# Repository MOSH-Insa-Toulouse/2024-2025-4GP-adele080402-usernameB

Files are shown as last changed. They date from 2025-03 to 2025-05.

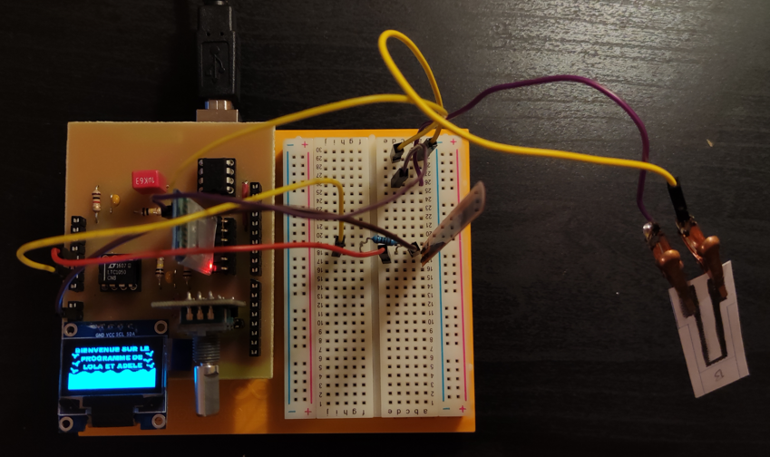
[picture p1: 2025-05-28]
Images Projet/Montage_arduino.png

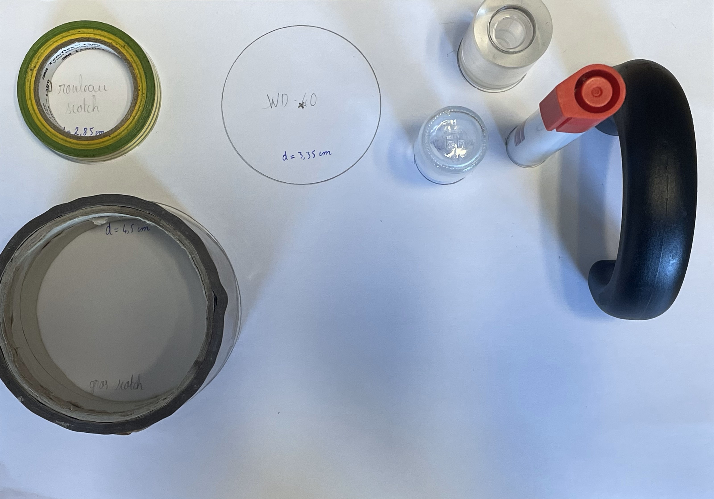
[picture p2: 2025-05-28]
Images Projet/Banc-de-test.jpg

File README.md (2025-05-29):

# PROJET CAPTEUR

## Sommaire
- [Description du projet](#description-du-projet)
- [Livrables](#livrables)
- [Matériel utilisé](#matériel-utilisé)
- [Simulation du montage sur LTSpice](#simulation-du-montage-sur-ltspice)
- [Création du PCB](#création-du-pcb)  
    -[KiCad](#kicad)  
    -[Schéma complet](#kicad)  
    -[Impression du PCB](#impression-du-pcb)  
- [Code Arduino](#code-arduino)
- [Application Android](#application-android)
- [Datasheet](#datasheet)
- [Tests de notre capteur et relevé de valeurs](#tests-de-notre-capteur-et-relevé-de-valeurs)
- [Contact](#contact)

## Description du projet

Nous avons réalisé ce projet dans le cadre de l'UF "du capteur au banc de test en open source hardware", en 4ème année de Génie Physique à l'INSA de Toulouse.
Le but de ce projet, basé sur l'article "Pencil Drawn Strain Gauges and Chemiresistors on Paper" (Cheng-Wei Lin, Zhibo Zhao, Jaemyung Kim & Jiaxing Huang), est de réaliser et tester un capteur low-tech, et d'évaluer son fonctionnement par rapport à un capteur commercialisé, afin de voir s'il est lui-même industrialisable. Le capteur concerné s'apparente à une jauge de contrainte, réalisée avec du papier recouvert d'une couche de graphite.  
Pour ce faire, nous avons réalisé un PCB à partir du logiciel KiCad, que nous avons pu intégrer à une carte Arduino UNO. Cela nous a permis d'effectuer des mesures et de tester notre capteur.

## Livrables

- PCB Shield adapté à l'Arduino Uno
- Code Arduino complet
- Banc de test du capteur
- Application Android fonctionnant par Bluetooth
- Datasheet du capteur

## Matériel utilisé

- Écran OLED : SSD1306
- Flex sensor
- Capteur Graphène
- Encodeur Rotatoire : KY-040
- Module Bluetooth HC-05
- Amplificateur Opérationnel : LCT-1050
- Potentiomètre Digital : MCP 41050
- Résistances : 1kOhms, 10kOhms, 100kOhms
- Capacités : 2x100nF, 1x1uF

## Simulation du montage sur LTSpice

Avant de commencer la réalisation concrète de notre projet, nous avons réalisé le montage qui sera réalisé physiquement sur [LTSpice](./LTSpice). Cette simulation nous a permis de comprendre comment l'arduino Uno pouvait acquérir les données du capteur. En effet, sans mettre en place un circuit transimpédance, nous ne serions pas en capacité d'acquérir des valeurs de résistance aussi élevées (k-M Ohms), puisque le courant résultant à acquérir avec un générateur 5V est très faible.

montage avec capteur image

## Création du PCB
### KiCad

Pour commencer le projet, nous avons dû nous familiariser avec le logiciel KiCad. Au début, nous avons eu du mal à assimiler les différentes étapes à effectuer, à cause de la diversité de ces dernières dans le logiciel KiCad. Nous avons finalement réussi à imprimer notre PCB dans les temps et sans problème. 
Premièrement, nous avons dû reprendre le circuit que nous avions réalisé sur LTSpice qui simulait le circuit final.  

Nous avons pris ce modèle pour réaliser la [partie schématique](./KiCad-Shield-Uno-FlexSensor) sur KiCad. Nous avons modélisé le circuit amplificateur, ainsi que différents dispositifs également présents sur notre PCB : 

- le [potentiomètre digital](./KiCad-Shield-Uno-FlexSensor/MaLibrairieEmpreinte.pretty)  

- l'[encodeur rotatoire](./KiCad-Shield-Uno-FlexSensor/MaLibrairieEmpreinte.pretty) 

- l'[écran OLED](./KiCad-Shield-Uno-FlexSensor/MaLibrairieEmpreinte.pretty)

- le [module Bluetooth](./KiCad-Shield-Uno-FlexSensor/MaLibrairieEmpreinte.pretty)
  
- l'[amplificateur opérationnel LTC41050](./KiCad-Shield-Uno-FlexSensor/MaLibrairieEmpreinte.pretty)

Ensuite, lorsque nous avons terminé le schématique, nous avons pu passer à l'organisation des éléments du PCB. Après avoir créé les empreintes et importer les bons modèles 3D des différents éléments, nous avons dû disposer de manière la plus optimale ces derniers. Cette étape a été un peu longue et nous avons dû recommencer plusieurs fois afin de limiter le nombre de vias et trouver la meilleure organisation possible. Nous avons finalement réussi à réaliser notre PCB avec seulement 3 vias. Nous avons également utilisé un plan de masse afin de simplifier le circuit.   
Une fois validé, nous avons pu passer à l'impression.

### Schéma complet

Schématique du PCB

                                            Schématique du PCB

Routage terminé du PCB

                                          Routage terminé du PCB
                                          
Modèle 3D du PCB (face avant)

                                          Modèle 3D du PCB (face avant)
                                            
Modèle 3D du PCB (face arrière)

                                          Modèle 3D du PCB (face arrière)

### Impression du PCB

Pour imprimer le PCB, nous avons dû télécharger le fichier [.gerber](./KiCad-Shield-Uno-FlexSensor/Gerber/KiCad-Shield-Uno-FlexSensor-B_Cu.pdf). Nous avons envoyé tous nos fichiers KiCad à Catherine Crouzet, qui nous a donné rendez-vous au GEI. Sur place, elle nous a expliqué toute la procédure. Le développement a été fait grâce au masque (fichier Gerber) placé sur une plaquette vierge et passé aux UVs, puis aux bains de développement.  
Une fois la plaquette dessinée, nous sommes allées percer la plaquette (les diamètres sont de 0,8mm pour les composants, et 1mm pour les pins de l'Arduino) sur laquelle nous avons soudé tous les composants. Cette partie était relativement rapide.



                                             Fichier Gerber
                                             


                                              PCB imprimé
                                              
PCB-avec-composants-avant

                                      PCB avec les composants soudés

## Code Arduino

Nous avons ensuite rédigé le [code](./arduino_code_capteur/arduino_code_capteur.ino) .ino, écrit en C++.   
Pour ce faire, nous nous sommes inspirées des codes étudiés durant les TPs/TDs tout au long du deuxième semestre, qui nous ont permis de mieux comprendre comment fonctionnait chaque composant.  
Nous avons rédigé les codes de chaque composant indépendamment afin de pouvoir les tester un à un, puis nous avons écrit le code en rajoutant peu à peu les codes fonctionnels et en les reliant les uns aux autres.

Le plus difficile à coder était l'encodeur rotatoire. Nous avons essayé de nombreuses fois, en nous inspirant des codes des années précédentes, ou des codes présents sur internet comme [Passion Électronique](https://passionelectronique.fr/encodeur-rotatif-incremental-mecanique/).  
Cependant, nous n'avons pas réussi à écrire un code fonctionnel qui nous permettait de naviguer entre les menus que nous avions créés. Nous avons décidé de garder les menus pour les différents composants (flex sensor, graphite sensor et potentiomètre digital) dans le code, pour pouvoir y accéder si besoin, ainsi que si de prochaines personnes voulaient essayer de rajouter la navigation entre les menus.   
Nous avons néanmoins voulu utiliser l'encodeur rotatoire, donc nous avons ajouté une fonction permettant de faire varier la valeur du potentiomètre digital grâce à l'encodeur.  

Nous n'avons malheureusement pas eu le loisir d'être très créatives car nous avons passé beaucoup de temps à décortiquer le fonctionnement et l'écriture du code pour chaque composant. Nous avons tout de même souhaité personnaliser notre projet en rajoutant un écran d'accueil à l'initialisation de l'écran OLED, qu'on peut voir sur la photo ci-dessous. 

E´cran_accueil_OLED

                                              Écran d'accueil de l'OLED

## Application Android

Pour l'[application Android](./Application Android), nous avons rencontré de nombreux problèmes au cours de son développement sur [MIT App Inventor](https://appinventor.mit.edu/). Le premier était simplement un problème d'affichage des données récupérer sur le graphique intéractif. Mais par la suite, nous ne pouvions même plus connecter notre téléphone à l'application, ce qui a nettement ralenti le développement de cette dernière, ainsi que son résultat final.  
Nous avons finalement une application à laquelle nous pouvons nous connecter, qui récupère les données affichées simultanément sur l'écran OLED, trace un graphique en temps réel, et contient un bouton RESET.

Écran_app_graphe_bonformat

                                              Interface de l'application Android

## Datasheet

Pour écrire la [datasheet](./Datasheet_capteur.pdf), nous avons décrit toutes les spécifités de notre capteur, tout en essayant de bien en expliquer son fonctionnement. Nous nous sommes basées sur les datasheets que nous avons pu étudier en cours au début du semestre, ainsi que toutes celles utilisées dans le cadre de nos études ou vies personnelles. La datasheet donne également un exemple d'application que l'on a expérimenté  au cours de ce projet.

## Tests de notre capteur et relevé de valeurs

Capture d'écran 2025-05-22 152802

Capture d'écran 2025-05-22 152732

Pour les relevés de valeur, nous avons rencontré un problème de consistance dans les mesures.
Le banc de test n'étant pas disponible lors de nos relevés de mesure, nous avons dû improviser et tester le capteur avec des objets circulaires dont le diamètre variait suffisamment pour avoir des données pertinentes. Ci-dessous est une photo des objets que nous avons utilisés.

Banc-de-test

                                        Objets utilisés pour le banc de test et leurs diamètres

Nous avons essayé de suivre un protocole de mesure afin d'avoir les mesures les plus pertinentes possible. Cependant, nous n'avons pas eu des mesures très satisfaisantes. 
Plus la mine de crayon est dure (2H), plus le capteur va être sensible et les valeurs vont fluctuer significativement, alors même que le capteur est immobile et qu'on n'y applique aucune déformation.
Inversement, plus la mine de crayon est grasse (6B), moins le capteur va être sensible et les valeurs vont rester très stables. On n'observera donc aucun changement de résistance, même en appliquant une forte déformation.

Aussi la manière de déposer le graphite influence beaucoup les valeurs obtenues.

Nous avons réussi à relever des valeurs uniquement pour les mines B et HB. Pour les autres mines testées, les valeurs n'étaient malheureusement pas pertinentes.

- HB : Mine avec laquelle le relevé de données a été concluant en compression mais moins en extension.
- B : Mine avec laquelle le relevé de données a été le plus concluant.
- 6B :Les valeurs de résistance mesurées avec cette mine restent bloquées à une valeur :  à 650 MOhms, même si la déformation appliquée est très importante.
- 2H : Les valeurs de résistance mesurées fluctuent trop, nous ne parvenons pas à avoir de données stables.

## Contact

Pour toute question ou information complémentaire, vous pouvez nous contacter :  
•Adèle Hovnanian, hovnanian@insa-toulouse.fr  
•Lola Grammont, grammont@insa-toulouse.fr

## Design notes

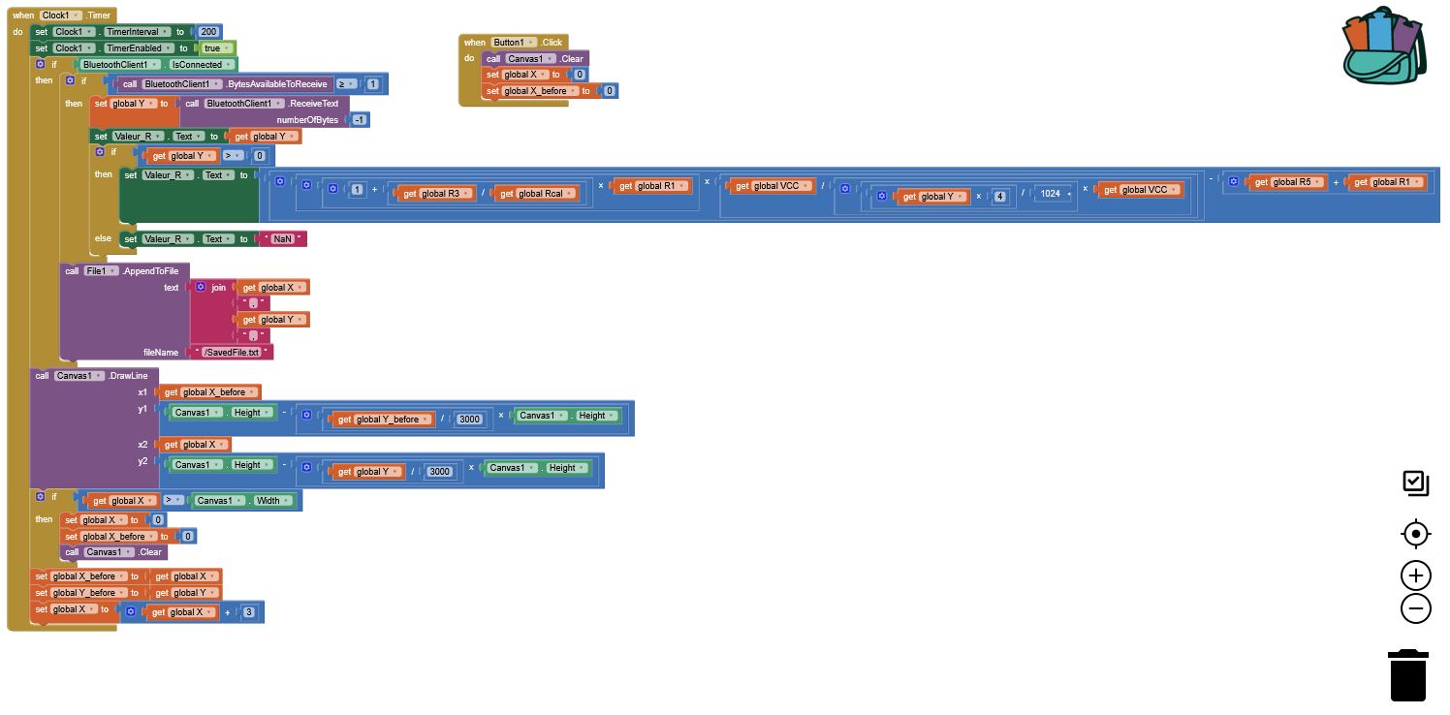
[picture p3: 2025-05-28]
Images Projet/application/Blocs_de_code_2.png

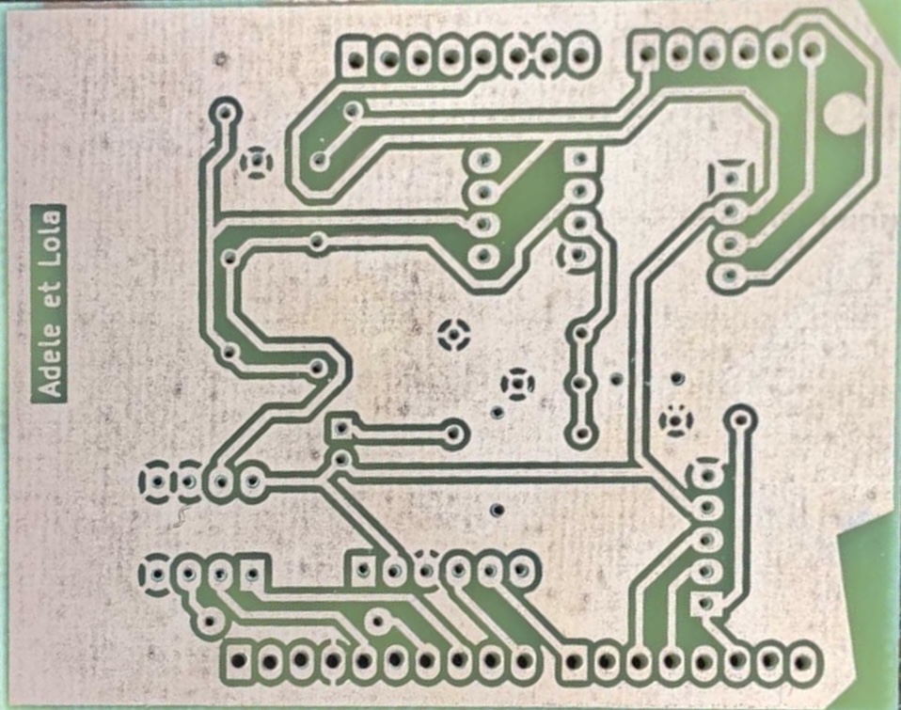
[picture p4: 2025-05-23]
Images Projet/PCB_imprime.jpg

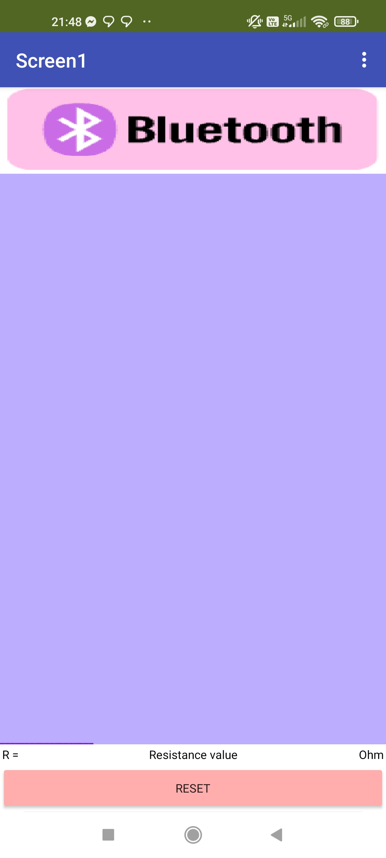
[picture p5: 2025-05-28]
Images Projet/application/Écran_app_vierge.jpg

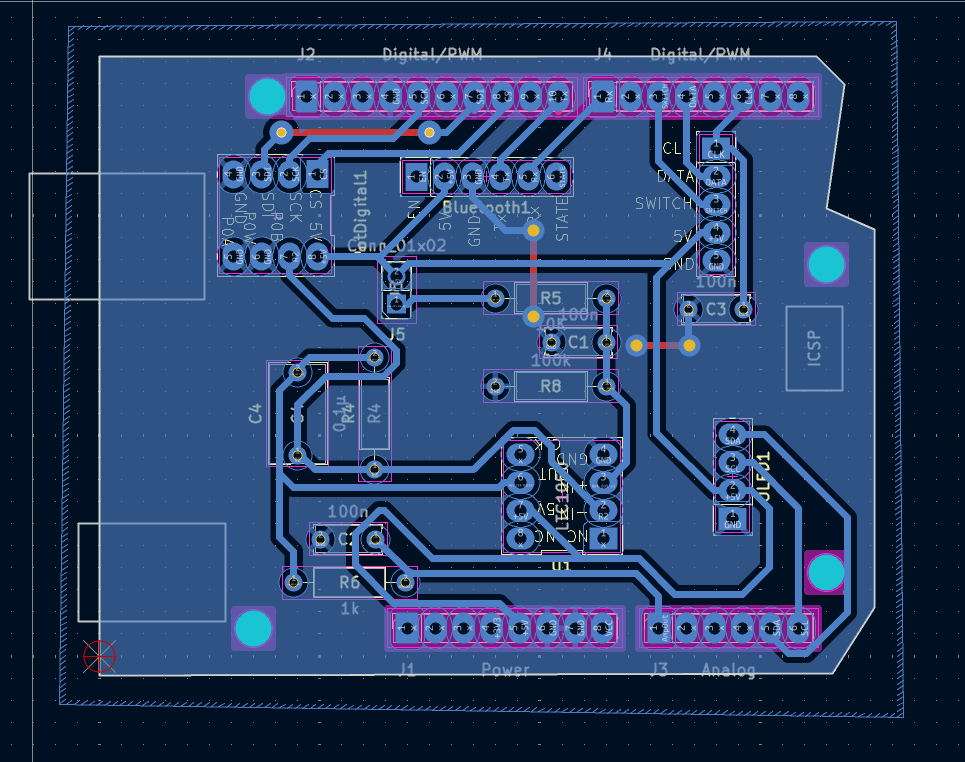
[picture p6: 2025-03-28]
Images Projet/Photos_kicad/Routage_KiCad.png

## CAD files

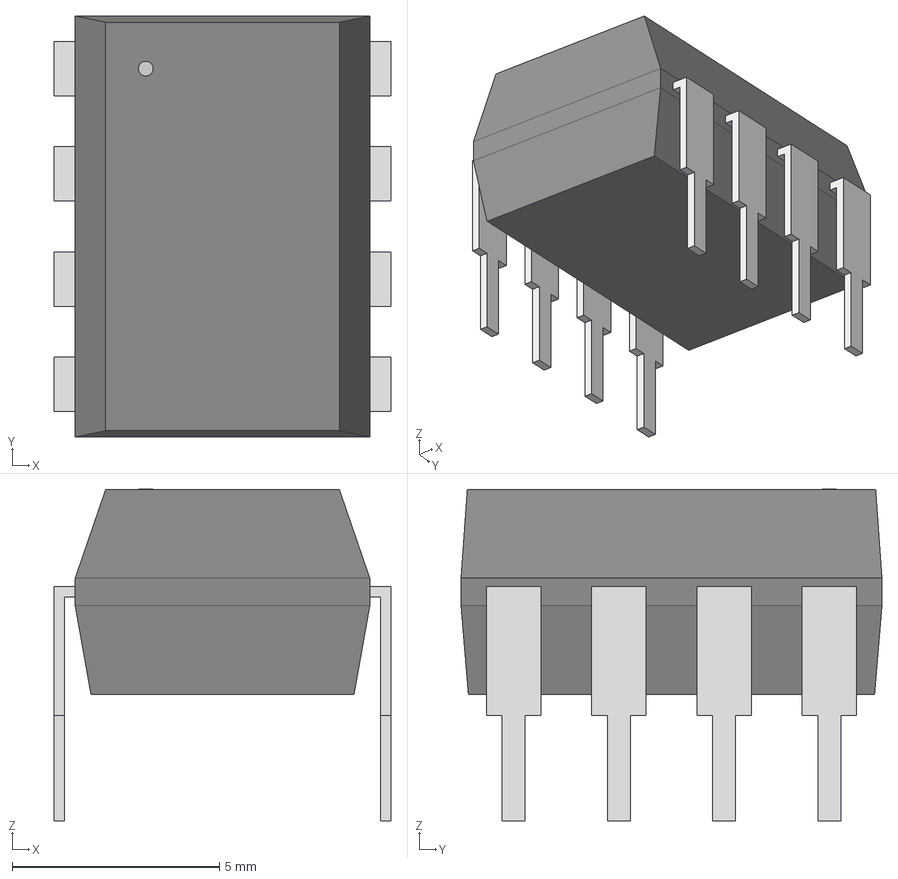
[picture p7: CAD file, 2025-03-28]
KiCad-Shield-Uno-FlexSensor/modeles_3D/MCP41050_E_P(1)/PDIP8_300MC_MCH.step
8.13 x 10.2 x 8.00 mm

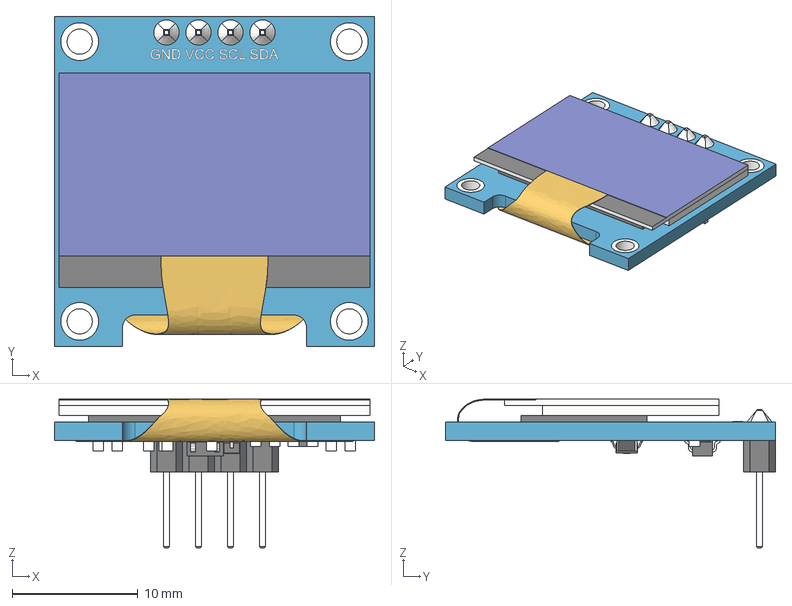
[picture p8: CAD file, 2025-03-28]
KiCad-Shield-Uno-FlexSensor/modeles_3D/SSD1306_OLED_Display(128x64).step
25.4 x 26.2 x 11.8 mm
board
screen
pin_header
soldering
smd_capacitor
smd_capacitor (1)
914_smd_resistor
472_smd_resistor x 3
t4_smd_diode
smd_capacitor (2)
smd_capacitor (3)
smd_capacitor (4)
smd_capacitor (5)
smd_capacitor (6)
472_smd_resistor (1)
SOT-23_XC6206 v3
smd_capacitor (7)
flat_cable

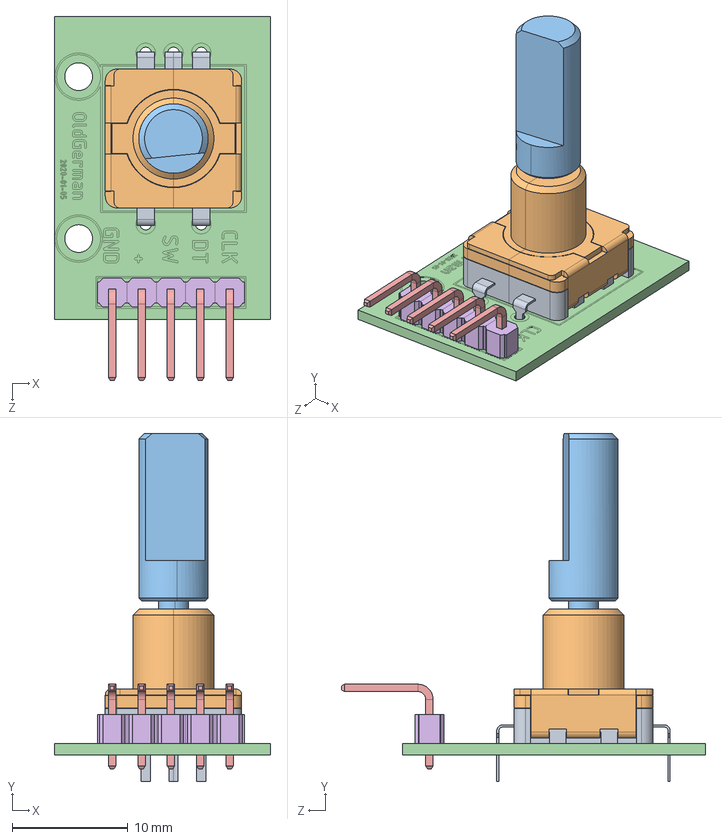
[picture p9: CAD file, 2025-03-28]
KiCad-Shield-Uno-FlexSensor/modeles_3D/KY-040 Rotary Encoder.STEP
18.7 x 30.1 x 31.5 mm
Rotary Encoder
D-handle
pcb
2.54 5PIN 90

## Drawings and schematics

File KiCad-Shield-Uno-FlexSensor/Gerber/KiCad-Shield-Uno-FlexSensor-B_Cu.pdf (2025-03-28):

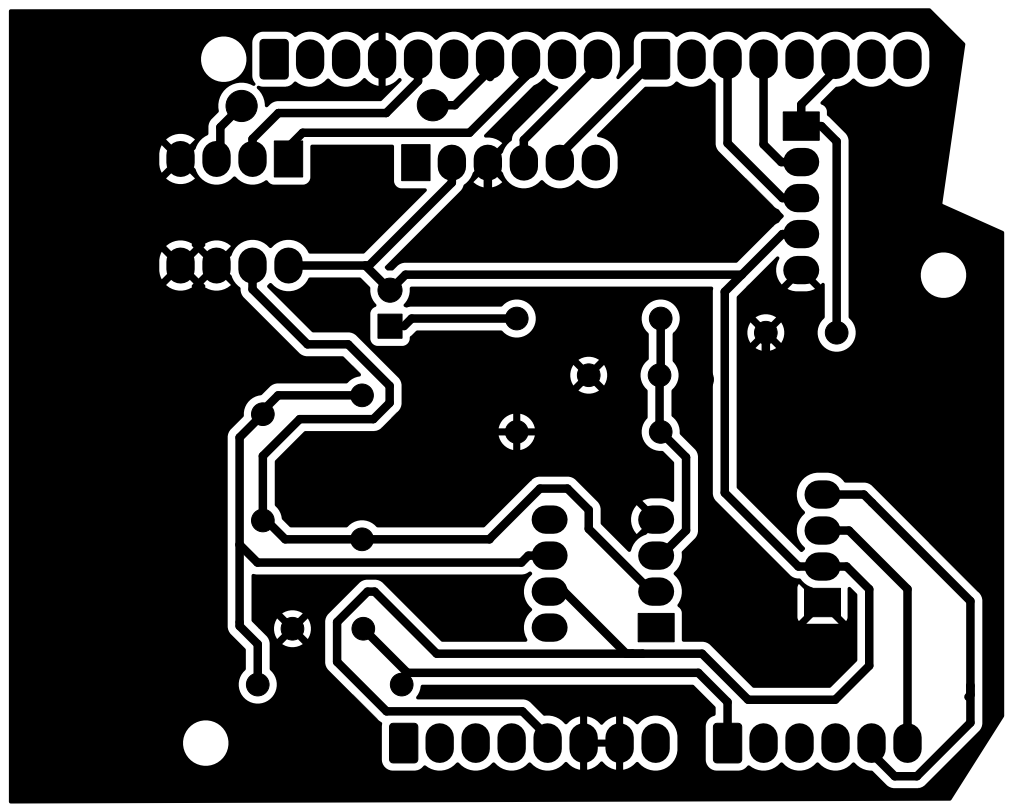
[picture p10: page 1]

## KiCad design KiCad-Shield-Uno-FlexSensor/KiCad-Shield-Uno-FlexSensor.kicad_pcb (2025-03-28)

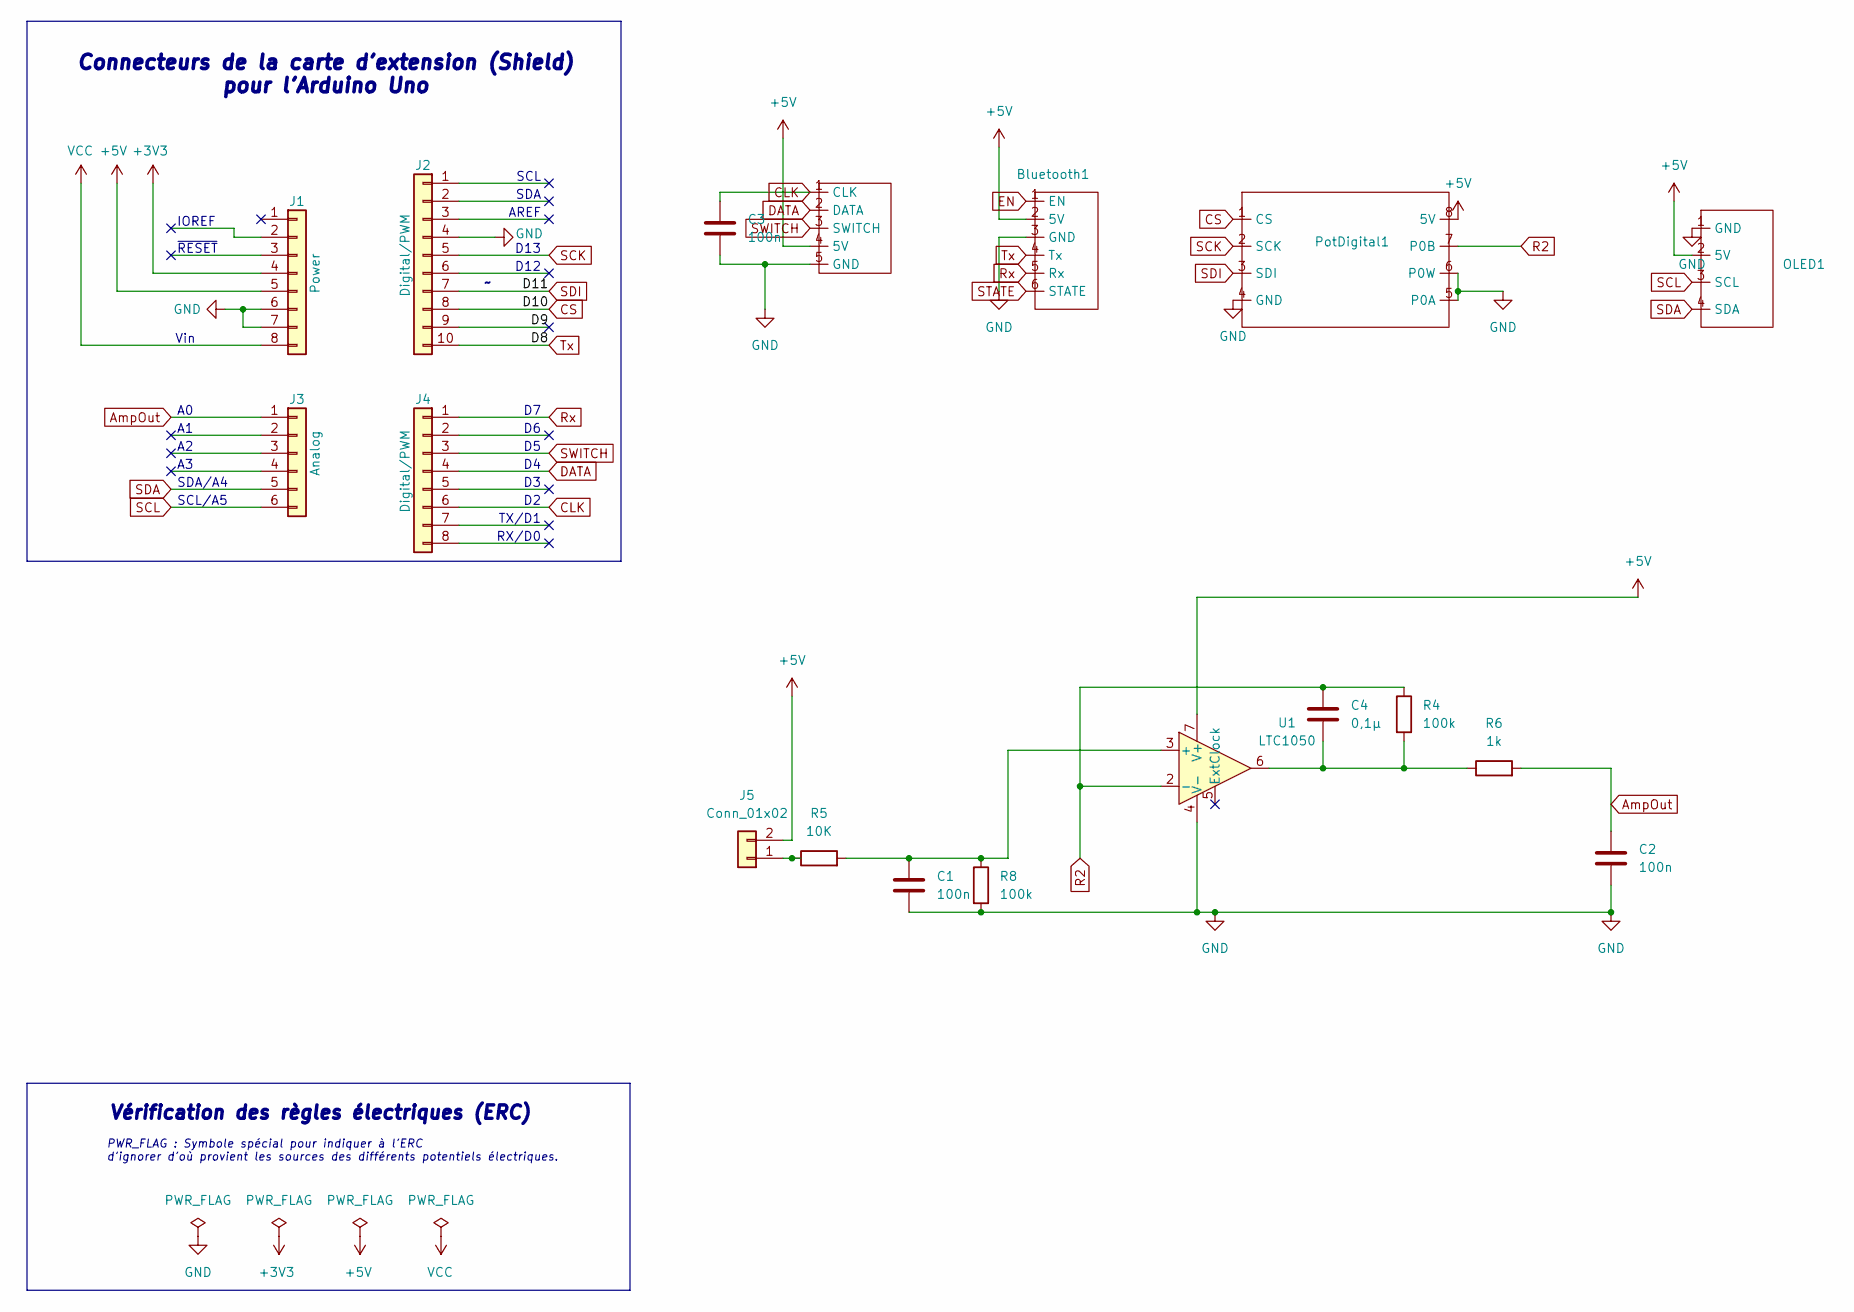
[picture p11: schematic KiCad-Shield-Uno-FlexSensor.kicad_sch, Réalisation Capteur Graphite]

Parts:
Bluetooth1: Bluetooth
C1, C2, C3: 100n; C_Disc_D6.0mm_W2.5mm_P5.00mm
C4: 0,1µ; C_Rect_L9.0mm_W5.1mm_P7.50mm_MKT
Encodeur_rotatoire1: EncodeurRotatoire
J1: Power; PinSocket_1x08_P2.54mm_Vertical
J2: Digital/PWM; PinSocket_1x10_P2.54mm_Vertical
J3: Analog; PinSocket_1x06_P2.54mm_Vertical
J4: Digital/PWM; PinSocket_1x08_P2.54mm_Vertical
J5: Conn_01x02; PinSocket_1x02_P2.54mm_Vertical
OLED1: OLED
PotDigital1: PotDigital
R4, R8: 100k; R_Axial_DIN0207_L6.3mm_D2.5mm_P10.16mm_Horizontal
R5: 10K; R_Axial_DIN0207_L6.3mm_D2.5mm_P10.16mm_Horizontal
R6: 1k; R_Axial_DIN0207_L6.3mm_D2.5mm_P10.16mm_Horizontal
U1: LTC1050; LTC41050

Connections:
+3V3: J1.4
+5V: Bluetooth1.2 (5V), Encodeur_rotatoire1.4 (5V), J1.5, J5.2, OLED1.2 (5V), PotDigital1.8 (5V), U1.7 (V+)
/D9: J2.9
AmpOut: C2.1, J3.1, R6.2
CLK: C3.1, Encodeur_rotatoire1.1 (CLK), J4.6
CS: J2.8, PotDigital1.1 (CS)
DATA: Encodeur_rotatoire1.2 (DATA), J4.4
EN: Bluetooth1.1 (EN)
GND: Bluetooth1.3 (GND), C1.2, C2.2, C3.2, Encodeur_rotatoire1.5 (GND), J1.6, J1.7, J2.4, OLED1.1 (GND), PotDigital1.4 (GND), PotDigital1.5 (P0A), PotDigital1.6 (P0W), R8.2, U1.4 (V-)
unnamed: C4.2, R4.2, R6.1, U1.6
unnamed: J5.1, R5.1
unnamed: C1.1, R5.2, R8.1, U1.3 (+)
R2: C4.1, PotDigital1.7 (P0B), R4.1, U1.2 (-)
Rx: Bluetooth1.5 (Rx), J4.1
SCK: J2.5, PotDigital1.2 (SCK)
SCL: J3.6, OLED1.3 (SCL)
SDA: J3.5, OLED1.4 (SDA)
SDI: J2.7, PotDigital1.3 (SDI)
STATE: Bluetooth1.6 (STATE)
SWITCH: Encodeur_rotatoire1.3 (SWITCH), J4.3
Tx: Bluetooth1.4 (Tx), J2.10
VCC: J1.8

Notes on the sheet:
AREF
SDA/A4
D12
~{RESET}
RX/D0
TX/D1
D13
Vin
SDA
Vérification des règles électriques (ERC)
Connecteurs de la carte d'extension (Shield) pour l'Arduino Uno
SCL/A5
SCL
IOREF
PWR_FLAG : Symbole spécial pour indiquer à l'ERC d'ignorer d'où provient les sources des différents potentiels électriques.

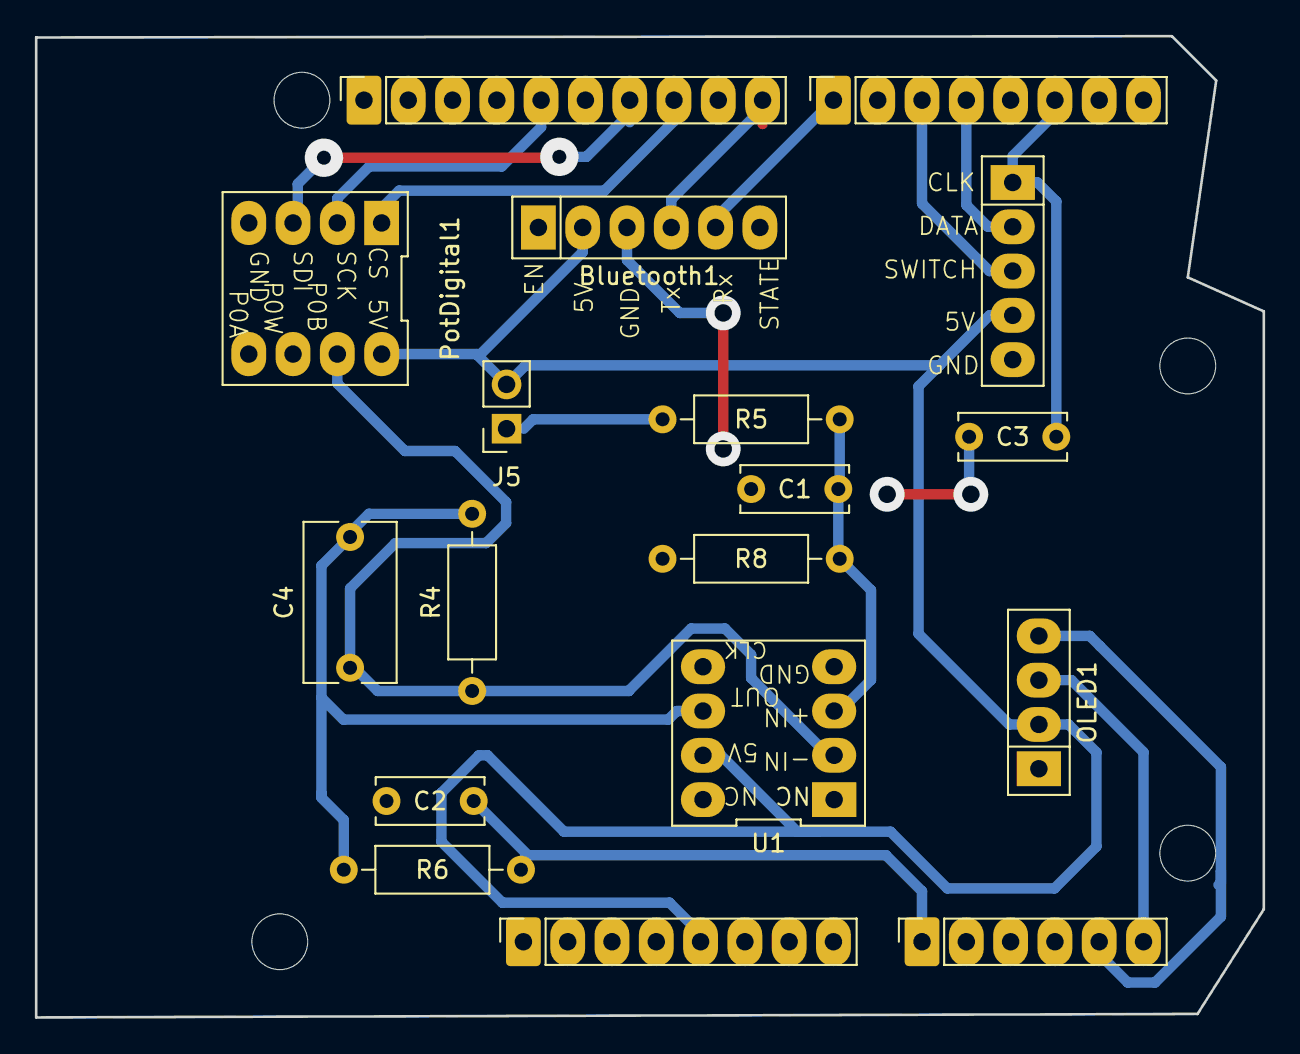
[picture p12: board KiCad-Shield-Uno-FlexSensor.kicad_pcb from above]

Board: 2 copper layers, 70.4 x 56.3 mm, 22 parts (0 on the bottom side), 17 nets.

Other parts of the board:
MH1, MH2, MH3, MH4: MountingHole_3.2mm

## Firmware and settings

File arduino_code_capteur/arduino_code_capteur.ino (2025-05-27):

////////////// INCLUSION DES BIBLIOTHEQUES////////////

#include <Adafruit_SSD1306.h>               // Bibliothèque de l'écran OLED
#include <SPI.h>                            // Bibliothèque pour communiquer avec le potentiomètre digital
#include <SoftwareSerial.h>                 // Bibliothèque pour gérer la communication avec l'appareil bluetooth

////////////// DEFINITION VARIABLES ////////////

// Ecran OLED
#define nombreDePixelsEnLargeur 128         // Taille de l'écran OLED, en pixel, au niveau de sa largeur
#define nombreDePixelsEnHauteur 64          // Taille de l'écran OLED, en pixel, au niveau de sa hauteur
#define brocheResetOLED         -1          // Reset de l'OLED partagé avec l'Arduino (d'où la valeur à -1, et non un numéro de pin)
#define adresseI2CecranOLED     0x3C        // Adresse de "mon" écran OLED sur le bus i2c (généralement égal à 0x3C ou 0x3D) 
Adafruit_SSD1306 ecranOLED(nombreDePixelsEnLargeur, nombreDePixelsEnHauteur, &Wire, brocheResetOLED);

// IMAGE ECRAN D'ACCUEIL
const unsigned char imageAccueil [] PROGMEM = {
	// 'BIENVENUE SUR LE PROGRAMME DE LOLA ET ADELE(3), 128x64px
  0x00, 0x00, 0x00, 0x00, 0x00, 0x00, 0x00, 0x00, 0x00, 0x00, 0x00, 0x00, 0x00, 0x00, 0x00, 0x00, 
	0x00, 0x00, 0x00, 0x00, 0x00, 0x00, 0x00, 0x00, 0x00, 0x00, 0x00, 0x00, 0x00, 0x00, 0x00, 0x00, 
	0x00, 0x00, 0x00, 0x00, 0x00, 0x00, 0x00, 0x00, 0x00, 0x00, 0x00, 0x00, 0x00, 0x00, 0x00, 0x00, 
	0x00, 0x00, 0x00, 0x00, 0x00, 0x00, 0x00, 0x00, 0x00, 0x00, 0x00, 0x00, 0x00, 0x00, 0x00, 0x00, 
	0x00, 0xf8, 0xdf, 0x98, 0xd8, 0xdf, 0xb9, 0x99, 0xdf, 0x83, 0xe6, 0x37, 0xe0, 0x61, 0xf8, 0x00, 
	0x00, 0xdc, 0xdf, 0x9c, 0xd9, 0x9f, 0xbd, 0x99, 0xdf, 0x83, 0x76, 0x37, 0xf0, 0x61, 0xf8, 0x00, 
	0x00, 0xcc, 0xdf, 0x9e, 0xdd, 0x9f, 0x3d, 0x99, 0xdf, 0x83, 0xc6, 0x37, 0x30, 0x61, 0xf8, 0x00, 
	0x00, 0xfc, 0xdf, 0x9f, 0xcd, 0x9f, 0x37, 0x99, 0xdf, 0x81, 0xf6, 0x37, 0xe0, 0x61, 0xf8, 0x00, 
	0x00, 0xcc, 0xdc, 0x1b, 0xcf, 0x18, 0x33, 0x99, 0x98, 0x07, 0x37, 0x77, 0x60, 0x61, 0xc0, 0x00, 
	0x00, 0xfc, 0xdf, 0x99, 0xc7, 0x1f, 0xb3, 0x9f, 0x9f, 0x83, 0xe3, 0xe7, 0x70, 0x7f, 0xfc, 0x00, 
	0x00, 0x00, 0x00, 0x00, 0x00, 0x00, 0x00, 0x00, 0x00, 0x00, 0x00, 0x00, 0x00, 0x00, 0x00, 0x00, 
	0x00, 0x00, 0x00, 0x00, 0x00, 0x00, 0x00, 0x00, 0x00, 0x00, 0x00, 0x00, 0x00, 0x00, 0x00, 0x10, 
	0x18, 0x30, 0x00, 0x00, 0x00, 0x00, 0x00, 0x00, 0x00, 0x00, 0x00, 0x00, 0x00, 0x00, 0x00, 0x70, 
	0x1e, 0xf8, 0x00, 0x00, 0x00, 0x00, 0x00, 0x00, 0x00, 0x00, 0x00, 0x00, 0x00, 0x00, 0x00, 0x60, 
	0x07, 0xc0, 0x00, 0x00, 0x00, 0x00, 0x00, 0x00, 0x00, 0x00, 0x00, 0x00, 0x00, 0x00, 0x7c, 0xc0, 
	0x03, 0x80, 0x00, 0x00, 0x00, 0x00, 0x00, 0x00, 0x00, 0x00, 0x00, 0x00, 0x00, 0x00, 0x1f, 0xc0, 
	0x03, 0x00, 0x00, 0x00, 0x30, 0x18, 0x00, 0x00, 0x00, 0x00, 0x00, 0x00, 0x00, 0x00, 0x03, 0xc0, 
	0x03, 0x00, 0x7e, 0xfe, 0xfc, 0x7e, 0x7e, 0x3c, 0xf7, 0xb9, 0xcf, 0xc3, 0xf3, 0xf0, 0x01, 0xc0, 
	0x00, 0x00, 0x66, 0xc6, 0xc6, 0xe6, 0x66, 0x3c, 0xf7, 0xbd, 0xcc, 0x03, 0x3b, 0x00, 0x00, 0x80, 
	0x00, 0x00, 0x7e, 0xfc, 0xc6, 0xce, 0x7e, 0x6c, 0xd7, 0xbf, 0xcf, 0x83, 0x1b, 0xf0, 0x00, 0x00, 
	0x00, 0x00, 0x7c, 0xdc, 0xc6, 0xc6, 0x6c, 0x7e, 0xdf, 0xbe, 0xcc, 0x03, 0x3b, 0x00, 0x00, 0x00, 
	0x00, 0x00, 0x60, 0xcc, 0xfe, 0x7e, 0x6e, 0xfe, 0xdf, 0xb6, 0xcf, 0xc3, 0xf3, 0xf0, 0x00, 0x00, 
	0x00, 0x00, 0x60, 0xce, 0x38, 0x3a, 0x66, 0xc7, 0xcb, 0xb6, 0xcf, 0xc3, 0xe3, 0xf0, 0x00, 0x00, 
	0x00, 0x0e, 0x00, 0x00, 0x00, 0x00, 0x00, 0x00, 0x00, 0x00, 0x00, 0x00, 0x00, 0x03, 0xc3, 0xe0, 
	0x00, 0x1c, 0x00, 0x00, 0x00, 0x00, 0x00, 0x00, 0x00, 0x00, 0x00, 0x00, 0x00, 0x03, 0xf7, 0x00, 
	0x0c, 0x38, 0x00, 0x00, 0x00, 0x00, 0x00, 0x00, 0x00, 0x00, 0x00, 0x00, 0x00, 0x00, 0x3e, 0x00, 
	0x0f, 0xf0, 0x00, 0x00, 0x00, 0x00, 0x00, 0x00, 0x00, 0x00, 0x00, 0x00, 0x00, 0x00, 0x1c, 0x00, 
	0x00, 0xf0, 0x00, 0x00, 0x00, 0x00, 0x00, 0x00, 0x00, 0x00, 0x00, 0x00, 0x00, 0x00, 0x08, 0x00, 
	0x00, 0x70, 0x00, 0x00, 0x00, 0x00, 0x00, 0x00, 0x00, 0x00, 0x00, 0x00, 0x00, 0x00, 0x00, 0x00, 
	0x00, 0x30, 0x06, 0x0f, 0xcc, 0x0e, 0x03, 0xf7, 0xe0, 0x78, 0xf9, 0xfd, 0x83, 0xf0, 0x00, 0x0c, 
	0x00, 0x00, 0x06, 0x1c, 0xcc, 0x0f, 0x03, 0x01, 0x80, 0x78, 0xcd, 0xc1, 0x83, 0x00, 0x00, 0x1c, 
	0x00, 0x00, 0x06, 0x18, 0xec, 0x1b, 0x03, 0xe1, 0x80, 0x78, 0xcd, 0xf9, 0x83, 0xe0, 0x18, 0x30, 
	0x00, 0x00, 0x06, 0x18, 0xec, 0x1b, 0x83, 0x01, 0x80, 0xcc, 0xcd, 0xc1, 0x83, 0x00, 0x1f, 0xb0, 
	0x30, 0x00, 0x07, 0xef, 0xcf, 0xff, 0x83, 0xf1, 0x80, 0xfc, 0xfd, 0xfd, 0xfb, 0xf0, 0x01, 0xf0, 
	0x38, 0x00, 0x07, 0xe7, 0x8f, 0xf1, 0x83, 0xf1, 0x81, 0xce, 0xf9, 0xfd, 0xfb, 0xf0, 0x00, 0xf0, 
	0x1c, 0x00, 0x00, 0x00, 0x00, 0x00, 0x00, 0x00, 0x00, 0x00, 0x00, 0x00, 0x00, 0x00, 0x00, 0x70, 
	0x06, 0xf8, 0x00, 0x00, 0x00, 0x00, 0x00, 0x00, 0x00, 0x00, 0x00, 0x00, 0x00, 0x00, 0x00, 0x00, 
	0x07, 0xf0, 0x00, 0x00, 0x00, 0x00, 0x00, 0x00, 0x00, 0x00, 0x00, 0x00, 0x00, 0x00, 0x00, 0x03, 
	0x07, 0x80, 0x00, 0x00, 0x00, 0x00, 0x00, 0x0c, 0x00, 0x00, 0x1f, 0x80, 0x00, 0x06, 0x00, 0x0f, 
	0x07, 0x00, 0x1f, 0x80, 0x03, 0xf8, 0x00, 0x7f, 0x80, 0x00, 0x7f, 0xe0, 0x00, 0x7f, 0xc0, 0x3f, 
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
};

// Module bluetooth
#define rxPin 8 //Broche 8 en tant que RX, a raccorder sur TX du HC-05
#define txPin 7 //Broche 7 en tant que RX, a raccorder sur TX du HC-05
SoftwareSerial Bluetooth(rxPin ,txPin); //Definition du software serial

// Flex Sensor commercial
const int flexPin = A1;
const float VCC = 5.0;                    // Tension de l'arduino
const float R_DIV = 10000.0;              // resistance pour créer le pont diviseur de tension
const float flatResistance = 36000.0;     // resistance quand le flex est à plat
const float bendResistance = 102000.0;    // resistance quand le flex est courbé à 90 degrés
const float kohm = 0.001;                 //convertit la resistance en kohms (simplifie l'affichage)
char buffer_flex[15];
char tabFlex[15];

//Graphite sensor
const int graphPin = A0;
const float R8 = 100000;
const float R4 = 100000;
float R2 = 50000;               //Valeur du potentiomètre digital à l'initialisation
const float R5 = 10000;
const float Mohm = 0.000001;
char buffer[15];
char tabGraphite[15];


// Digital Potentiometer
#define CSpin 10
#define SDIpin 11
#define SCKpin 13
#define MCP_NOP 0b00000000
#define MCP_WRITE 0b00010001
#define MCP_SHTDWN 0b00100001
const byte address = 0x11;
int pos = 0;                                   // pour déterminer R2 (potentiomètre) (0<pos<255) , plus pos -> 0, plus R2 est grand
int lastA = LOW;

// Rotatory Encoder 
#define encoder0pinA 2
#define encoder0pinB 4
#define SWITCHpin 5
volatile unsigned int encoder0Pos = 0;


#define baudrate 9600

void setup() {

  Serial.begin(baudrate);
  Bluetooth.begin(baudrate);

  // Initialisation de l'écran OLED
  if(!ecranOLED.begin(SSD1306_SWITCHCAPVCC, adresseI2CecranOLED)){
    while(1);                                                           // Arrêt du programme (boucle infinie) si échec d'initialisation
  }
  
  ecranOLED.clearDisplay();                                            // Effaçage de l'intégralité du buffer

  ecranOLED.drawBitmap( 0,0,imageAccueil,nombreDePixelsEnLargeur, nombreDePixelsEnHauteur,WHITE);
  ecranOLED.display();
  delay(1000);
  ecranOLED.clearDisplay();

  // Initialisation pins
  pinMode(rxPin,INPUT);
  pinMode(txPin,OUTPUT);
  pinMode(flexPin, INPUT);
  pinMode(CSpin, OUTPUT);
  pinMode(encoder0pinA,INPUT);
  pinMode(encoder0pinB,INPUT);
  // pinMode(SWITCHpin, INPUT);



  //Potentiometer setup
  digitalWrite(CSpin,HIGH); //SPI chip disabled
  SPI.begin();
  int R2 = digitalPotWrite(pos);

  //Encodeur rotatoire setup
  digitalWrite(encoder0pinA, HIGH);
  digitalWrite(encoder0pinB, HIGH);
  attachInterrupt(0,doEncoder,RISING);

}

//////////////Digital Potentiometer///////////////////////////

float digitalPotWrite (int value){

  digitalWrite(CSpin, LOW);
  SPI.transfer(address);
  SPI.transfer(value);
  digitalWrite(CSpin, HIGH);
  float Rdp = (50000.0 * (255 - value)) / 255.0; 
  Serial.println(Rdp);
  return Rdp;
}

///////////////////Measure/////////////////////////////////////////

float flexMeasure() {

  int ADCflex = analogRead(flexPin);                                          // Lit la tension ADC pour calculer la résistance
  float Vflex = ADCflex * VCC / 1024.0;
  float Rflex = (R_DIV * (VCC / Vflex - 1.0))*kohm;
  Serial.println("Resistance : " + String(Rflex) + " kohms");
  float angle = map(Rflex/kohm, flatResistance, bendResistance, 0, 90.0);     // Utilise la résistance calculée pour avoir l'angle
  Serial.println("Bend : " + String(angle) + " degrees");
  Serial.println();
  delay(100);
  return angle;
}

float graphiteMeasure () {

  float V = analogRead(graphPin);
  Serial.println("V =" + String(V));
  float Vadc = V*5.0/1024.0;
  Serial.println("Vadc =" + String(Vadc));
  float Rg = (R8*(1+R4/R2)*(VCC/Vadc)-R8-R5)*kohm;
  Serial.println("Rgraphite ="+ String(Rg) + "kohms");
  delay(200);
  return V;

}

//////////////BLUETOOTH/////////////////////////////

void bluetoothData () {

  float Vgraphite = graphiteMeasure() * 5.0/1024.0;
  float Rg = (R8*(1+R4/R2)*(VCC/Vgraphite)-R8-R5)*kohm;
  float Vflex = analogRead(flexPin) *5.0/1024;
  float Rflex = (R_DIV * (5 / Vflex - 1.0))*kohm;

  dtostrf(Rg, 4, 2, buffer);
  sprintf(tabGraphite, "%s\n", buffer);
  Bluetooth.print(tabGraphite);

  // Serial.println(tabGraphite);
}


/////////////// FONCTIONS DISPLAY MENUS////////////////////
void principalMenu() {

  ecranOLED.clearDisplay();
  ecranOLED.setCursor(0, 0);
  int tailleDeCaractere=1;
  ecranOLED.setTextColor(SSD1306_WHITE, SSD1306_BLACK); // Couleur du texte, et couleur du fond
  ecranOLED.setTextSize(tailleDeCaractere);
  ecranOLED.println("Graphite Sensor");
  ecranOLED.println("Flex Sensor");
  ecranOLED.println("Digital Potentiometer");
  ecranOLED.display();
  
}

void graphiteMenu(float V) {

  ecranOLED.clearDisplay(); // Effaçage de l'intégralité du buffer
  ecranOLED.setCursor(0, 0);

  int tailleDeCaractere=1;
  float Vadc = V*5.0/1024;

  ecranOLED.setTextColor(SSD1306_WHITE, SSD1306_BLACK); // Couleur du texte, et couleur du fond
  ecranOLED.setTextSize(tailleDeCaractere);
  ecranOLED.println("--Menu GraphSensor--");
  ecranOLED.println();
  ecranOLED.print("Tension =");
  ecranOLED.println(Vadc);
  ecranOLED.print("R =");
  ecranOLED.print((R8*(1+R4/R2)*(VCC/Vadc)-R8-R5)*kohm);
  ecranOLED.println(" kOhm");
  ecranOLED.println();
  ecranOLED.print("             BACK");
  ecranOLED.display(); // Transfert le buffer à l'écran
  delay(200);
  ecranOLED.clearDisplay();
  ecranOLED.setCursor(0, 0);
}

void flexMenu(float angle) {

  int ADCflex = analogRead(flexPin);
  float Vflex = ADCflex * VCC / 1023.0;
  int tailleDeCaractere=1;
  
  ecranOLED.clearDisplay();
  ecranOLED.setCursor(0, 0);

  ecranOLED.setTextColor(SSD1306_WHITE, SSD1306_BLACK); // Couleur du texte, et couleur du fond
  ecranOLED.setTextSize(tailleDeCaractere);
  ecranOLED.println(" --Menu FlexSensor--");
  ecranOLED.println();
  ecranOLED.print("R=");
  ecranOLED.println(String((R_DIV * (VCC / Vflex - 1.0))*kohm) +"Kohms");
  ecranOLED.print("Angle =");
  ecranOLED.println(String(angle) + "degrees");
  ecranOLED.println();
  ecranOLED.print("             BACK");

  delay(500);
  ecranOLED.display();
}

void potMenu(float Rdp) {

  ecranOLED.clearDisplay();
  ecranOLED.setCursor(0, 0);
  int tailleDeCaractere = 1;

  ecranOLED.setTextColor(SSD1306_WHITE, SSD1306_BLACK); // Couleur du texte, et couleur du fond
  ecranOLED.setTextSize(tailleDeCaractere);
  ecranOLED.println("-Menu Potentiometre-");
  ecranOLED.println();
  ecranOLED.print("Rdp =");                           //Résistance choisie pour le potentiomètre digital
  ecranOLED.println(String(Rdp)+"ohms");
  ecranOLED.println();
  ecranOLED.println();
  ecranOLED.print("             BACK");

  ecranOLED.display();
  
}
//////////////////////////////////////////////////////////////////////////////

///////////////////////// Encodeur Rotatoire //////////////////////////////////

void doEncoder() {

  int currentA = digitalRead(encoder0pinA);
  if (currentA != lastA && currentA == HIGH) {
    if (digitalRead(encoder0pinB) == LOW) {
      pos++;                                    // sens horaire
    } else {
      pos--;                                    // sens anti-horaire
    }
  }
    // Limites
  if (pos > 255) pos = 255;
  if (pos < 0) pos = 0;
  lastA = currentA;
}

////////////////////////////////////////////////////////////////////////////////

void loop() {

doEncoder();

// graphiteMenu(graphiteMeasure());
// delay(5000);
// flexMenu(flexMeasure());
// delay(5000);
potMenu(digitalPotWrite(pos));
// delay(5000);
// bluetoothData();

}

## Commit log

2025-02-21 Ajout de ma todolist
2025-03-28 Fichiers Kicad finaux
    [KY-040 Rotary Encoder.STEP, KiCad-Shield-Uno-FlexSensor.kicad_pcb, KiCad-Shield-Uno-FlexSensor.kicad_sch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]
2025-04-08 Commencement du code pour l'arduino
    [KiCad-Shield-Uno-FlexSensor.kicad_sch]
2025-04-19 commencement de l'écriture du fichier README
2025-04-19 nettoyage dossier
    [KY-040 Rotary Encoder.STEP, KiCad_v9_.kicad_pcb, KiCad_v9_.kicad_sch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]
2025-05-15 rajout de quelques modifs fichier README
2025-05-27 Rename Capture d'écran 2025-03-28 103835.png to PCB_kicad.png
2025-05-27 Rajout de l'application et misde à jour du code
2025-05-28 Nettoyage des fichiers
    [KY-040 Rotary Encoder.STEP, PDIP8_300MC_MCH.step, SSD1306_OLED_Display(128x64).step]
2025-05-28 Rename Capture d’écran 2025-05-28 à 15.44.57.png to Écran_app_graphe_bonformat.png
2025-05-28 rajout relevé valeurs
    [Relevés capteurs graphites.xlsx]
